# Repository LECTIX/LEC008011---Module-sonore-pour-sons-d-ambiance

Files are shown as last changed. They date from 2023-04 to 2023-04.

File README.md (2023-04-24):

# LEC008011 - Module sonore pour sons d’ambiance
Fichiers sources pour le produit LEC008011

## Description du produit

Branchez jusqu’à 14 boutons poussoirs, ILS, relais ou encore pédales de contact pour déclencher des sons personnalisés et donner vie à votre réseau.

## Utiliser les fichiers sources pour fabriquer le produit

Grâce aux fichiers sources publiés ici, vous pouvez être en mesure de faire fabriquer ce produit par un sous traitant.

**ATTENTION** ce produit est un **produit complexe à fabriquer** et nécessite notamment une programmation afin de pouvoir fonctionner. Vous devez pour cela posséder le programmateur et programmer vous même la carte. Cette étape peut nécessiter des connaissances techniques, si nécessaire, nous vous encourrageons à vous rapprocher d'un club.

**Remarque** ce produit est composé d'une carte mère, d'un haut parleur externe (8 ohm 1W, référence FS50MS0810-H7.5), d'une carte micro SD, et d'un module pour la gestion du son (DF-player mini). Ce dossier permet uniquement de faire fabriquer la carte mère, vous devrez vous fournir les autres composants sur un site de revente (amazon, aliexpress, mouser, ...).

### Faire fabriquer chez un sous traitant

Il est aujourd'hui possible de faire fabriquer à moindre cout des cartes électroniques. Nous recommendons [JLCPCB](https://jlcpcb.com/) si vous voulez aller au moins cher. Si vous préférez un acteur européen, [eurocircuits](https://www.eurocircuits.com/) est un des acteurs reconnus.

IMAGE ALT TEXT (http://www.youtube.com/watch?v=RXGGvsUtz0c "TUTO : faire fabriquer un produit LECTIX")

1. Télécherger les sources de ce produit en cliquant sur le bouton `Code`, puis `Download ZIP`.
1. Décompresser le dossier.
1. Les fichiers pour la fabrication se trouvent dans le répertoire `hardware/prod`.
1. Se connecter sur [https://cart.jlcpcb.com/quote](https://cart.jlcpcb.com/quote)
1. Cliquer sur le bouton `Add gerber file` et sélectionner le fichier `gerbers.zip`.
1. Sélectionnez la quantité de cartes que vous souhaitez dans le champs `PCB Qty`.
1. Laisser toutes les autres options par défaut, puis cliquez sur le toggle switch en face de `PCB Assembly`, et enfin sur le bouton `confirm`.
1. Une preview de la carte électronique sans les composants doit apparaitre. Cliquez sur `NEXT`.
1. Cliquez sur le bouton `Add BOM File`, puis sélectionnez le fichier `bom.csv`
1. Cliquez sur le bouton `Add CPL File`, puis sélectionnez le fichier `pos.csv`
1. **Vérifier que tous les composants sont en stock** et bien sélectionnés, puis cliquez sur `NEXT`.
1. Une preview de la carte avec ses composants apparait. Continuer le chemin en cliquant sur `NEXT`.
1. Le prix final apparait. Sélectionnez la catégorie du produit, puis cliquez sur `SAVE TO CART`.
1. Une fois sauvegardé dans votre panier, vous pouvez valider votre commande et choisir le moyen d'acheminement. Afin de ne pas avoir à se préoccuper des frais de douane, nous vous conseillons de choisir une méthode d'expédition DDP.

Vous receverez vos cartes sous 1 à 3 semaines. 

**Nous ne sommes en aucun cas responsables des cartes qui arriveraient défectueuses ou non fonctionnelles.**

### Modifications des fichiers sources

Installez kicad 6 (ou version supérieure), et ouvrez le fichier LEC008011.kicad_pro

### Programation

Pour programmer le module, vous devez posséder
- un programmateur AVR type USBASP
- Un adaptateur 10 pin vers 6 pin
- Un connecteur de type header 2 x 6 pour connecter l'adaptateur à la carte

Le firmware se trouve dans le dossier du même nom. Il est recommandé d'utiliser VS-code et platform-io pour programmer la carte. Pour ce faire, branchez le programmateur à votre PC et à la carte à programmer, puis rentrer les commandes suivantes :

```
cd firmware
platformio run --target fuses && platformio run --target upload
```

### Regénérer les fichiers gerber, BOM, et position (Optionnel)

Peut se faire simplement en utilisant kikit :

```
cd hardware
docker run --rm -w /kikit -v $PWD:/kikit yaqwsx/kikit kikit fab jlcpcb --assembly --no-drc --schematic LEC008011.kicad_sch --field LCSC --corrections JLCPCB_CORRECTION --nametemplate LEC008011_{} LEC008011.kicad_pcb prod/

```
## Notices
[Manuel FR](docs/manual_fr.pdf)

## License
Tous nos fichiers sont plubliés sous les licenses
- CERN Open Hardware Licence Version 2 - Strongly Reciprocal pour ce qui touche au hardware
- GNU General Public License v3.0 pour tout ce qui est software

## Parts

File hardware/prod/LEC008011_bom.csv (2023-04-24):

Comment | Designator | Footprint | LCSC
100uF | C1 | Capacitor_SMD:CP_Elec_6.3x7.7 | C249982
100nF | C2,C3,C4,C8 | Capacitor_SMD:C_0805_2012Metric | C49678
1000uF | C6 | Capacitor_SMD:CP_Elec_8x10.5 | C176671
MB10S | D1 | Package_TO_SOT_SMD:TO-269AA | C2488
LED | D2 | LED_SMD:LED_0603_1608Metric | C72043
100V 2A | D3 | Diode_SMD:D_SMA | C14996
Screw_Terminal_01x02 | J1 | 0_connectors:TerminalBlock_bornier-2_P5.08mm-green | C395849
Conn_02x03_Odd_Even | J3 | Connector_PinHeader_2.54mm:PinHeader_2x03_P2.54mm_Vertical | C5116479
Screw_Terminal_01x02 | J4,J5,J6,J7,J8,J9,J10,J11,J12 | 0_connectors:TerminalBlock_bornier-2_P5.08mm-blue | C395882
Conn_01x08_Male | J13,J14 | Connector_PinHeader_2.54mm:PinHeader_1x08_P2.54mm_Vertical | C27438
47uH | L1 | 0_inductors:JSHC0650-470M | C386872
10k | R1,R2 | Resistor_SMD:R_0805_2012Metric | C17414
1k | R3,R5 | Resistor_SMD:R_0805_2012Metric | C17513
3k | R4 | Resistor_SMD:R_0805_2012Metric | C17661
R_POT | RV1 | 0_potentiometers:Potentiometer_Bourns_TC33X_Vertical | C128547
XL1509-ADJE1 | U1 | Package_SO:SOP-8_3.76x4.96mm_P1.27mm | C74192
ATmega88PB-AU | U2 | Package_QFP:TQFP-32_7x7mm_P0.8mm | C8727

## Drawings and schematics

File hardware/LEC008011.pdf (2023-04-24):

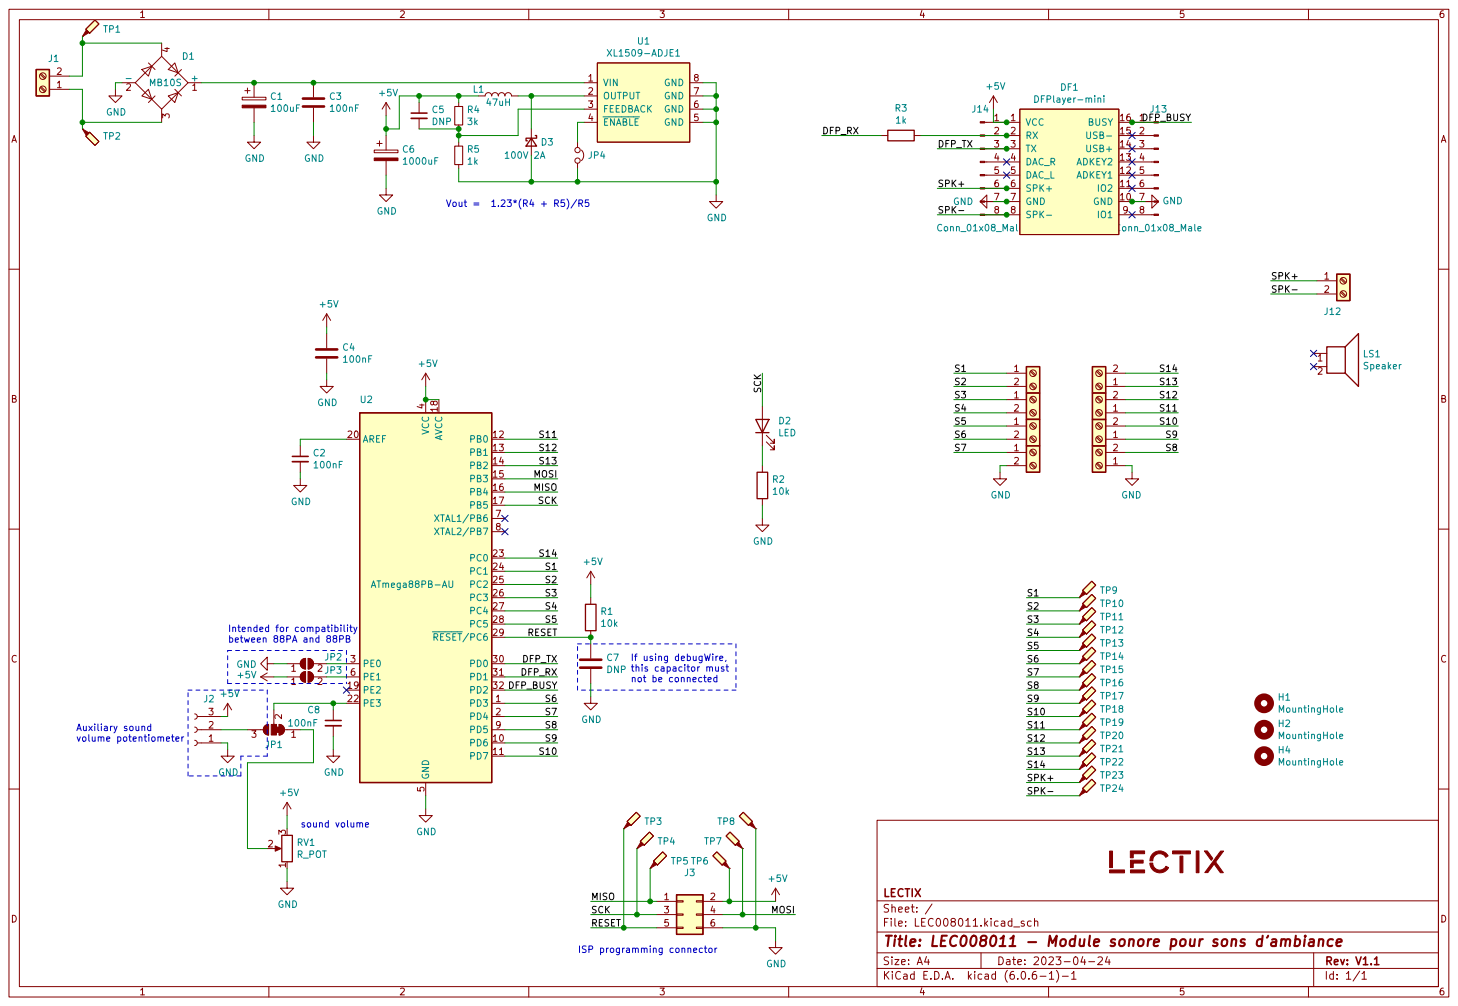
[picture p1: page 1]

Intended for compatibility between 88PA and 88PB

If using debugWire,
C7 DNP
this capacitor must not be connected

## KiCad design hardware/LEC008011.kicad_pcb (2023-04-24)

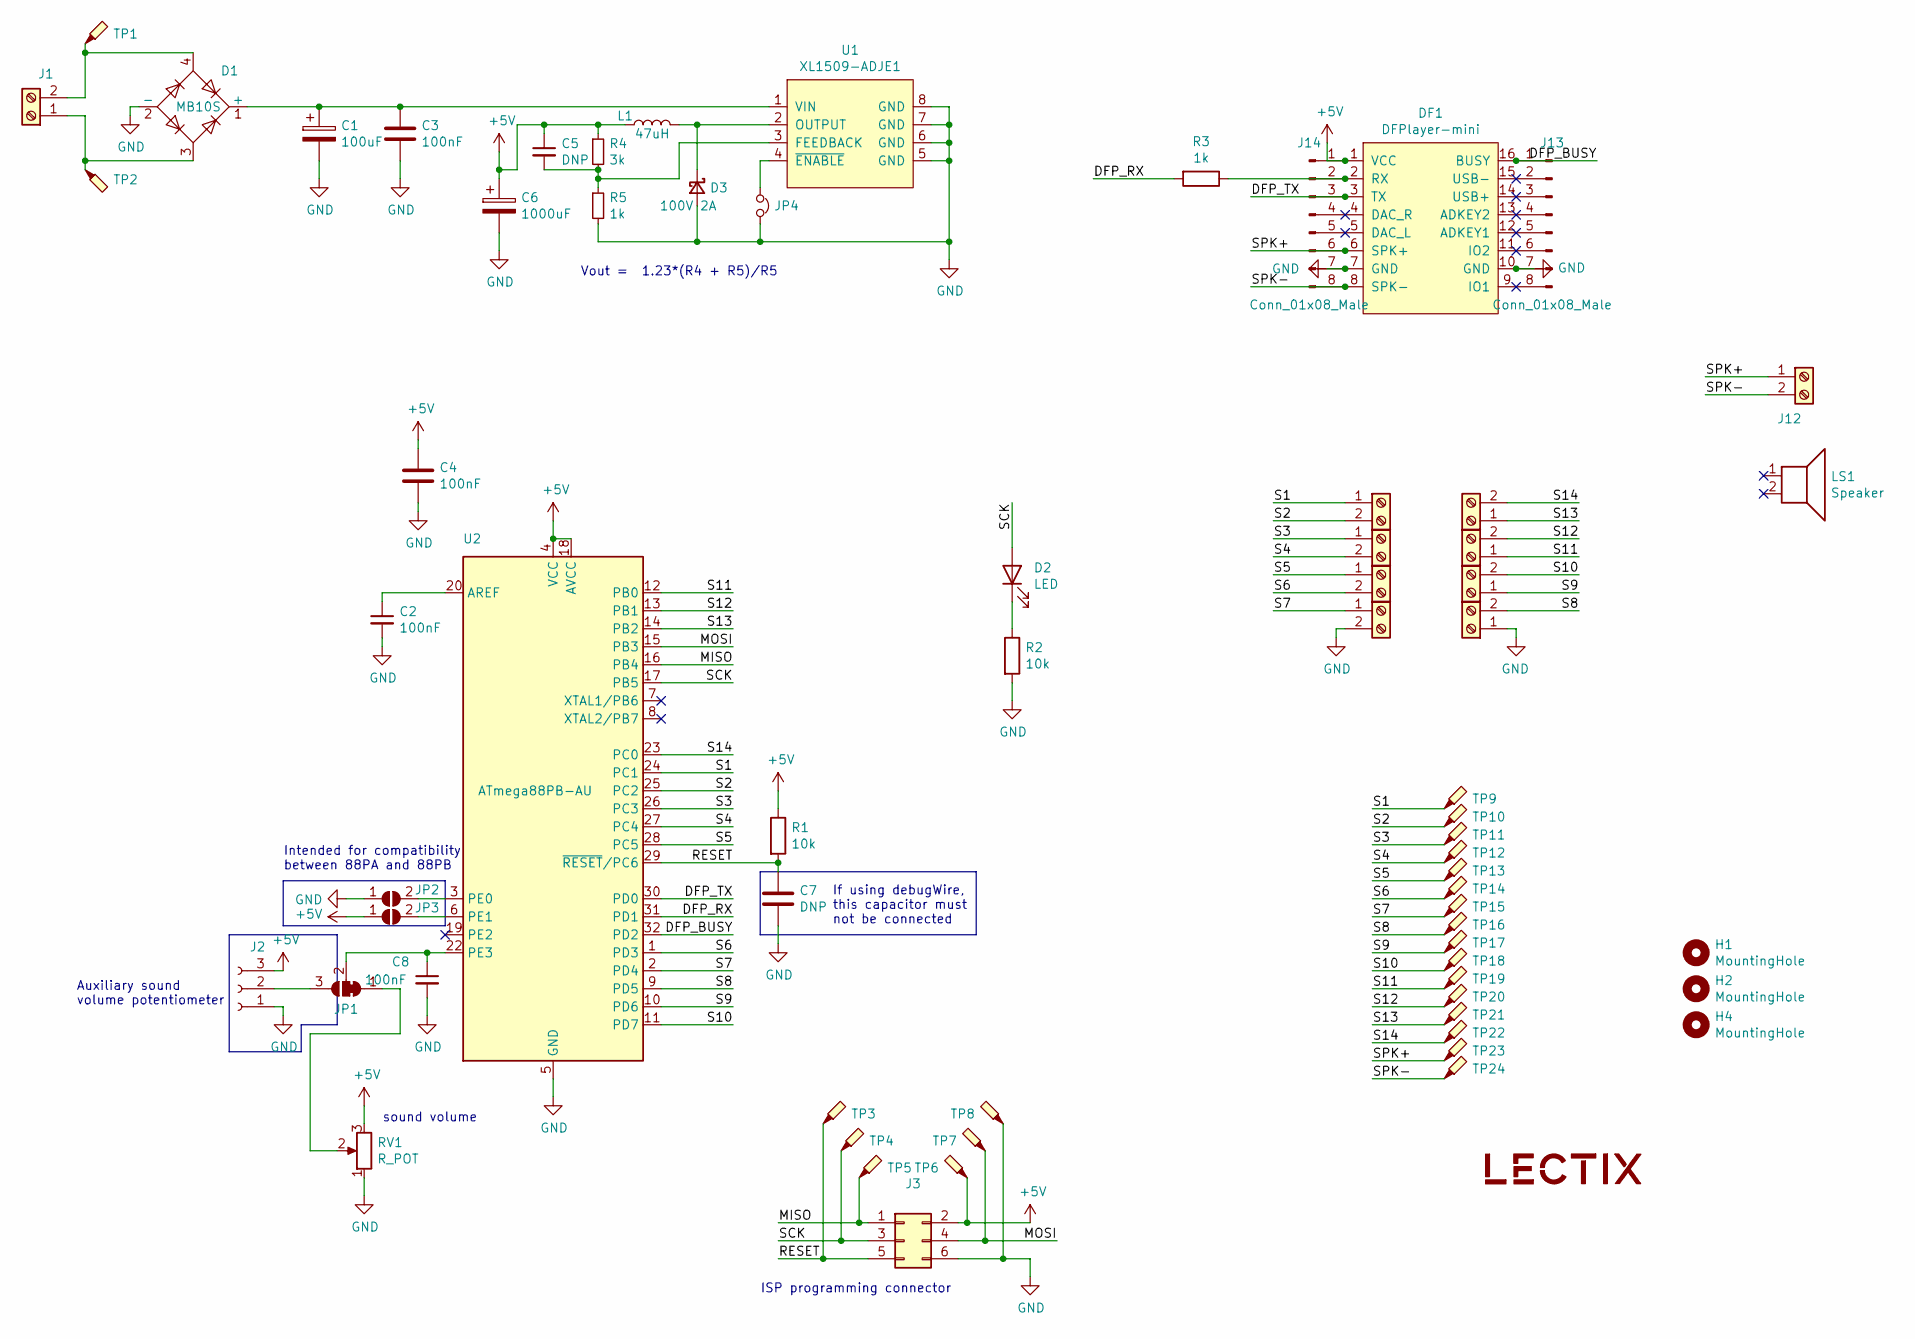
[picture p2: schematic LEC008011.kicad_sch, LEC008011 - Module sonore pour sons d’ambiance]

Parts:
C1: 100uF; CP_Elec_6.3x7.7; MPN VZT101M1VTR-0606; LCSC C249982
C2, C3, C4, C8: 100nF; C_0805_2012Metric; MPN CC0805KRX7R9BB104; LCSC C49678
C5, C7: DNP; C_0805_2012Metric; MPN DNP; LCSC DNP
C6: 1000uF; CP_Elec_8x10.5; MPN VEJ471M1CTR-0810; LCSC C176671
D1: MB10S; TO-269AA; MPN MB10S; LCSC C2488
D2: LED; LED_0603_1608Metric; MPN 19-217/GHC-YR1S2/3T; LCSC C72043
D3: 100V 2A; D_SMA; MPN SS210; LCSC C14996
DF1: DFPlayer-mini; DFPlayer; MPN Female Header 8P, 2.54mm pitch; LCSC C27438
H1, H2, H4: MountingHole; MountingHole_3.2mm_M3; MPN DNP; LCSC DNP
J1: Screw_Terminal_01x02; TerminalBlock_bornier-2_P5.08mm-green; MPN DB126V-5.0-2P-GN; LCSC C395849
J2: Conn_01x03_Female; SolderWirePad_1x03_P3.81mm_Drill1.2mm; MPN DNP; LCSC DNP
J3: Conn_02x03_Odd_Even; PinHeader_2x03_P2.54mm_Vertical; MPN DNP; LCSC C5116479
J4, J5, J6, J7, J8, J9, J10, J11, J12: Screw_Terminal_01x02; TerminalBlock_bornier-2_P5.08mm-blue; MPN DB301V-5.0-2P-BU-S; LCSC C395882
J13, J14: Conn_01x08_Male; PinHeader_1x08_P2.54mm_Vertical; LCSC C27438
JP1: SolderJumper_3_Bridged12; SolderJumper-3_P1.3mm_Bridged12_RoundedPad1.0x1.5mm; MPN DNP; LCSC DNP
JP2, JP3: SolderJumper_2_Open; SolderJumper-2_P1.3mm_Open_RoundedPad1.0x1.5mm; MPN DNP; LCSC DNP
JP4: Jumper_NC_Small; SolderJumper-2_P1.3mm_Bridged_RoundedPad1.0x1.5mm; MPN DNP; LCSC DNP
L1: 47uH; JSHC0650-470M; MPN JSHC0650-470M; LCSC C386872
LOGO1: logo_lectix_25mm; Logo_10mm; MPN DNP; LCSC DNP
LS1: Speaker; MPN FS50MS0810-H7.5; LCSC C482318
R1, R2: 10k; R_0805_2012Metric; MPN 0805W8F1002T5E; LCSC C17414
R3, R5: 1k; R_0805_2012Metric; MPN 0805W8F1001T5E; LCSC C17513
R4: 3k; R_0805_2012Metric; MPN 0805W8F3001T5E; LCSC C17661
RV1: R_POT; Potentiometer_Bourns_TC33X_Vertical; MPN VG039NCHXTB153; LCSC C128547
TP1, TP2, TP3, TP4, TP5, TP6, TP7, TP8, TP9, TP10, TP11, TP12, TP13, TP14, TP15, TP16, TP17, TP18, TP19, TP20, TP21, TP22, TP23, TP24: TestPoint_Probe; TestPoint_Pad_D1.0mm; MPN DNP; LCSC DNP
U1: XL1509-ADJE1; SOP-8_3.76x4.96mm_P1.27mm; MPN XL1509-ADJE1; LCSC C74192
U2: ATmega88PB-AU; TQFP-32_7x7mm_P0.8mm; MPN ATMEGA88PA-AU; LCSC C8727

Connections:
+5V: C4.1, C5.1, C6.1, DF1.1 (VCC), J2.3, J3.2, J14.1, JP3.1 (A), L1.1, R1.1, R4.1, RV1.3, TP6.1, U2.4 (VCC), U2.18 (AVCC)
/DFP_BUSY: DF1.16 (BUSY), J13.1, U2.32 (PD2)
/DFP_RX: R3.2, U2.31 (PD1)
/DFP_TX: DF1.3 (TX), J14.3, U2.30 (PD0)
/MISO: J3.1, TP5.1, U2.16 (PB4)
/MOSI: J3.4, TP7.1, U2.15 (PB3)
/RESET: C7.1, J3.5, R1.2, TP3.1, U2.29 (~RESET/PC6)
/S1: J4.1, TP9.1, U2.24 (PC1)
/S2: J4.2, TP10.1, U2.25 (PC2)
/S3: J5.1, TP11.1, U2.26 (PC3)
/S4: J5.2, TP12.1, U2.27 (PC4)
/S5: J6.1, TP13.1, U2.28 (PC5)
/S6: J6.2, TP14.1, U2.1 (PD3)
/S7: J7.1, TP15.1, U2.2 (PD4)
/S8: J11.2, TP16.1, U2.9 (PD5)
/S9: J10.1, TP17.1, U2.10 (PD6)
/S10: J10.2, TP18.1, U2.11 (PD7)
/S11: J9.1, TP19.1, U2.12 (PB0)
/S12: J9.2, TP20.1, U2.13 (PB1)
/S13: J8.1, TP21.1, U2.14 (PB2)
/S14: J8.2, TP22.1, U2.23 (PC0)
/SCK: D2.2 (A), J3.3, TP4.1, U2.17 (PB5)
/SPK+: DF1.6 (SPK+), J12.1, J14.6, TP23.1
/SPK-: DF1.8 (SPK-), J12.2, J14.8, TP24.1
GND: C1.2, C2.2, C3.2, C4.2, C6.2, C7.2, C8.2, D1.2 (-), D3.2 (A), DF1.7 (GND), DF1.10 (GND), J2.1, J3.6, J7.2, J11.1, J13.7, J14.7, JP2.1 (A), JP4.2, R2.2, R5.2, RV1.1, TP8.1, U1.5 (GND), U1.6 (GND), U1.7 (GND), U1.8 (GND), U2.5 (GND), U2.21 (GND)
unnamed: C1.1, C3.1, D1.1 (+), U1.1 (VIN)
unnamed: C2.1, U2.20 (AREF)
unnamed: C5.2, R4.2, R5.1, U1.3 (FEEDBACK)
unnamed: C8.1, JP1.2 (C), U2.22 (PE3)
unnamed: D1.3, J1.1, TP2.1
unnamed: D1.4, J1.2, TP1.1
unnamed: D2.1 (K), R2.1
unnamed: D3.1 (K), L1.2, U1.2 (OUTPUT)
unnamed: DF1.2 (RX), J14.2, R3.1
unnamed: DF1.4 (DAC_R), J14.4
unnamed: DF1.5 (DAC_L), J14.5
unnamed: DF1.9 (IO1), J13.8
unnamed: DF1.11 (IO2), J13.6
unnamed: DF1.12 (ADKEY1), J13.5
unnamed: DF1.13 (ADKEY2), J13.4
unnamed: DF1.14 (USB+), J13.3
unnamed: DF1.15 (USB-), J13.2
unnamed: J2.2, JP1.3 (B)
unnamed: JP1.1 (A), RV1.2
unnamed: JP2.2 (B), U2.3 (PE0)
unnamed: JP3.2 (B), U2.6 (PE1)
unnamed: JP4.1, U1.4 (~ENABLE)

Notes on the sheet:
sound volume
Vout = 1.23*(R4 + R5)/R5
Auxiliary sound volume potentiometer
If using debugWire, this capacitor must not be connected
ISP programming connector
Intended for compatibility between 88PA and 88PB

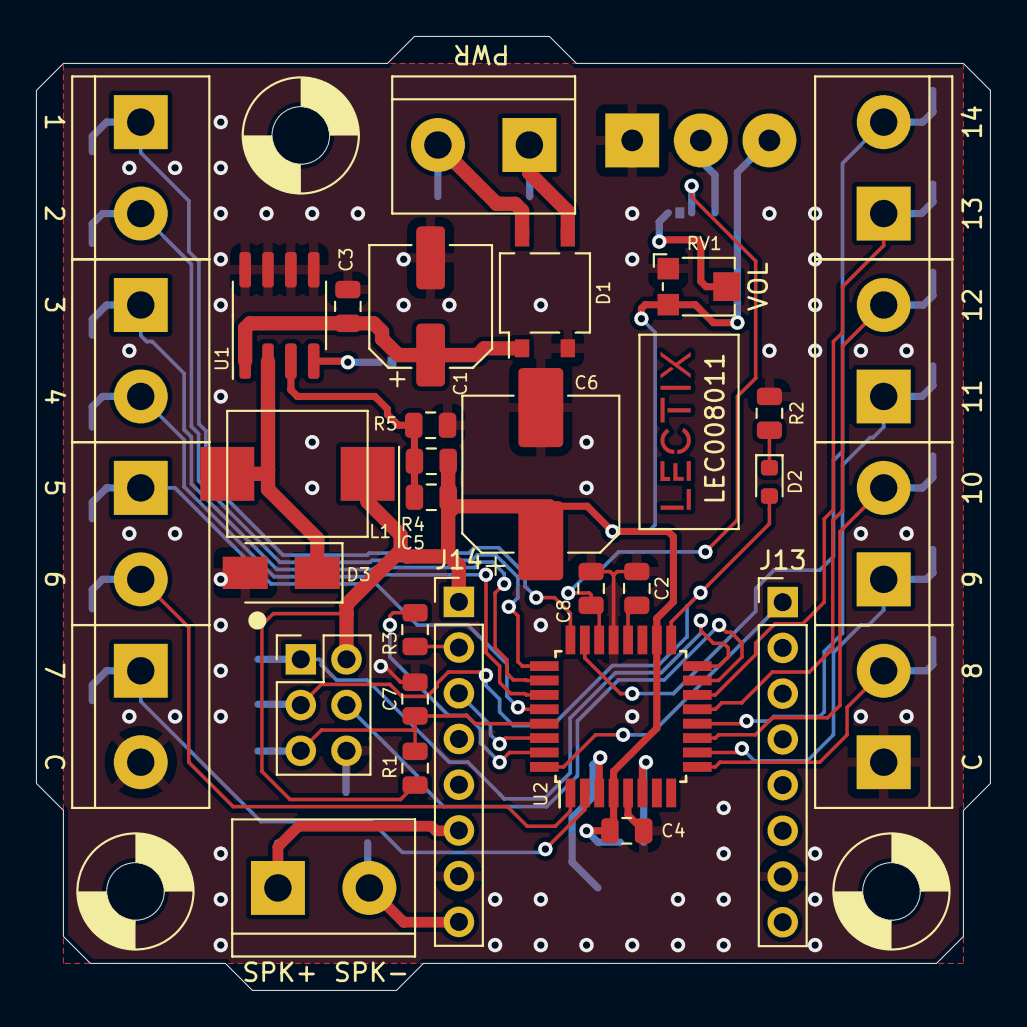
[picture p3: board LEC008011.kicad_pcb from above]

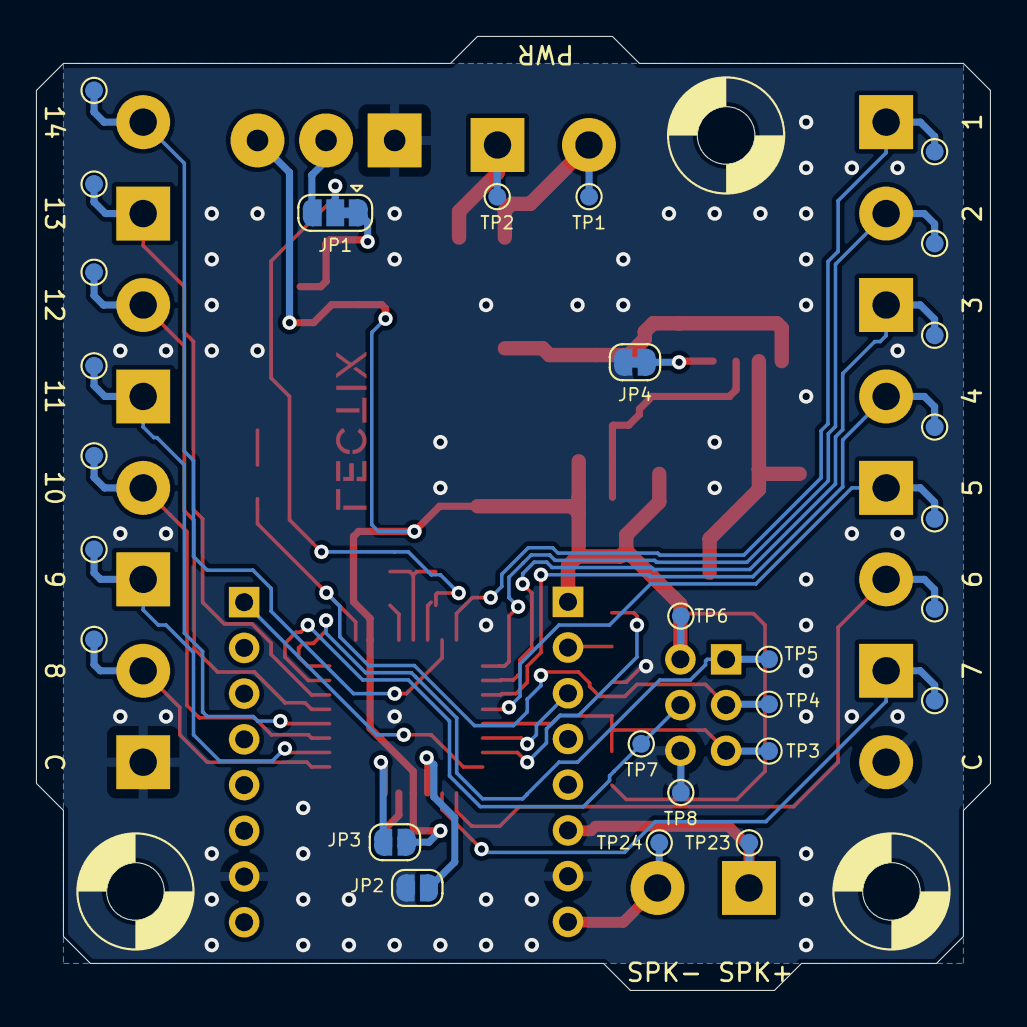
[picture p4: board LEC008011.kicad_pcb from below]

Board: 2 copper layers, 53.0 x 53.0 mm, 66 parts (28 on the bottom side), 39 nets.

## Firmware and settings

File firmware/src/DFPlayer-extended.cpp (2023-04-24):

#include "Arduino.h"
#include "SoftwareSerial.h"
#include "DFRobotDFPlayerMini.h"
#include "pin.h"
#include <Bounce2.h>

/**
 * LED errors codes : 
 *  1 flash (250 ms) = No SD card detected
 *  2 flashes (250 ms) = Cannot Find File
 *  3 flashes (250 ms) = File Index Out of Bound
 *  4 flashes (250 ms) = Check Sum Not Match
 *  5 flashes (250 ms) = Get Wrong Stack
 *  6 flashes (250 ms) = Sleeping
 *  7 flashes (250 ms) = In Advertise
 *  10 flashes (250 ms) = Time Out!
 *  11 flashes (250 ms) = Stack Wrong!
 *  14 flashes (250 ms) = Card Online!
 *  15 flashes (250 ms) = USB Inserted!
 *  16 flashes (250 ms) = USB Removed!
 * 
 */

void (*resetFunc)(void) = 0;
long mapWithHysteresis(long x, long in_min, long in_max, long out_min, long out_max, byte threshold = 0);
void updateVolume();
void handleErrors(uint8_t type, int value);
void flashLED(int nbFlashs);

DFRobotDFPlayerMini myDFPlayer;
Bounce *switches = new Bounce[NB_SWITCHES];
void printDetail(uint8_t type, int value);

void setup()
{
  pinMode(PIN_LED, OUTPUT);
  pinMode(PIN_DFP_BUSY, INPUT);
  pinMode(PIN_SOUND_VOL, INPUT);

  for (int i = 0; i < NB_SWITCHES; i++)
  {
    switches[i].attach(PIN_SWITCHES[i], INPUT_PULLUP); //setup the bounce instance for the current button
    switches[i].interval(25);                          // interval in ms
  }

  delay(1000);

  Serial.begin(9600);

  if (!myDFPlayer.begin(Serial))
  {
    handleErrors(myDFPlayer.readType(), myDFPlayer.read());
    resetFunc();
  }

  digitalWrite(PIN_LED, HIGH);

  // Player init
  myDFPlayer.setTimeOut(500); //Set serial communictaion time out 500ms
  updateVolume();
  myDFPlayer.EQ(DFPLAYER_EQ_NORMAL);
  myDFPlayer.outputDevice(DFPLAYER_DEVICE_SD);
}

void loop()
{
  static unsigned long timer = millis();

  for (int i = 0; i < NB_SWITCHES; i++)
  {
    switches[i].update();
    if (switches[i].fell())
    {
      myDFPlayer.playMp3Folder(i + 1);
    }
  }

  if (millis() - timer > 100)
  {
    timer = millis();
    updateVolume();
  }

  if (myDFPlayer.available())
  {
    handleErrors(myDFPlayer.readType(), myDFPlayer.read());
  }
}

long mapWithHysteresis(long x, long in_min, long in_max, long out_min, long out_max, byte threshold)
{
  static long lastX = x;

  if (abs(lastX - x) > threshold)
  {
    lastX = x;
    return (x - in_min) * (out_max - out_min) / (in_max - in_min) + out_min;
  }
  else
    return (lastX - in_min) * (out_max - out_min) / (in_max - in_min) + out_min;
}

void updateVolume()
{
  static int volume = -1;
  int vol = analogRead(PIN_SOUND_VOL);
  vol = mapWithHysteresis(vol, 0, 1023, 0, 30, 15);
  if (vol != volume)
  {
    // digitalWrite(PIN_LED, vol & 0x01);
    volume = vol;
    myDFPlayer.volume(vol);
  }
}

void handleErrors(uint8_t type, int value)
{
  switch (type)
  {
  case TimeOut: // Time Out!
    flashLED(10);
    break;
  case WrongStack: // Stack Wrong!
    flashLED(11);
    break;
  case DFPlayerCardInserted: // Card Inserted!
    // flashLED(12);
    break;
  case DFPlayerCardRemoved: // Card Removed!
    flashLED(1);
    resetFunc();
    // flashLED(13);
    break;
  case DFPlayerCardOnline: // Card Online!
    // flashLED(14);
    break;
  case DFPlayerUSBInserted: // USB Inserted!
    flashLED(15);
    break;
  case DFPlayerUSBRemoved: // USB Removed!
    flashLED(16);
    break;
  case DFPlayerPlayFinished: // Play Finished!
    digitalWrite(PIN_LED, HIGH);
    // flashLED(17);
    break;
  case DFPlayerError: // DFPlayerError
    switch (value)
    {
    case Busy: // card not found
      flashLED(1);
      resetFunc();
      break;
    case Sleeping: // Sleeping
      flashLED(6);
      break;
    case SerialWrongStack: // Get Wrong Stack
      flashLED(5);
      break;
    case CheckSumNotMatch: // Check Sum Not Match
      flashLED(4);
      break;
    case FileIndexOut: // File Index Out of Bound
      flashLED(3);
      break;
    case FileMismatch: // Cannot Find File
      flashLED(2);
      break;
    case Advertise: // In Advertise
      flashLED(7);
      break;
    default:
      break;
    }
    break;
  default:
    break;
  }
}

void flashLED(int nbFlashs)
{
  digitalWrite(PIN_LED, LOW);
  delay(1000);
  for (int i = 0; i < nbFlashs; ++i)
  {
    digitalWrite(PIN_LED, HIGH);
    delay(250);
    digitalWrite(PIN_LED, LOW);
    delay(250);
  }
}

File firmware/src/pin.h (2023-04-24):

#ifndef PIN_H
#define PIN_H

#define NB_SWITCHES     14

#define PIN_LED         13    // PB5
#define PIN_DFP_TX      0     // PD0
#define PIN_DFP_RX      1     // PD1
#define PIN_DFP_BUSY    2     // PD2
const uint8_t PIN_SWITCHES[NB_SWITCHES] = {15, 16, 17, 18, 19, 3, 4, 5, 6, 7, 8, 9, 10, 14};
#define PIN_SOUND_VOL   A7    // PE3

#endif

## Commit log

2023-04-24 Add hardware source files
    [LEC008011-CmtUser.gbr, LEC008011-CuBottom.gbl, LEC008011-CuTop.gtl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]
2023-04-24 Add pdf schematic file
